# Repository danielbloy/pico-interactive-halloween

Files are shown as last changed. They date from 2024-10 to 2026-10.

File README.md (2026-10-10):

# pico-interactive-halloween

Please see my website [Code Club Adventures](http://codeclubadventures.com/) for more coding
materials.

This project has been moved from https://github.com/danielbloy/pico-interactive/halloween/2024

These videos don't quite do it justice but are good enough to get an idea
of what the finished halloween projects look like.

Halloween
2025 [notes](./2025.md), [pictures](showcase/2025/overview.md), [video on YouTube](https://www.youtube.com/shorts/VWgEQCHVglk)

Halloween 2024 [notes](./2024.md), [video on YouTube](https://youtu.be/h3QauCqTOTw)

Halloween 2023 [video on YouTube](https://youtu.be/a0I0U5x334Y), the full code for Halloween 2023
can be
found at https://github.com/danielbloy/pico-interactive-origins.

My daughter loves Halloween and after Halloween 2022 (she was 8 years old at the
time) we discussed using some of the electronics that I use in my Coding Clubs to
make our house more interactive with sounds and lights. I agreed to this because
how hard could it possibly be? Well it turns out it was a massive undertaking and
very stressful! But she loved it and that was all that mattered.

Once over, we decided to go bigger for 2024 and fix a number of the issues we had
with the 2023 setup. As I knew it'd be a bunch of work I started earlier (March
2024). It was still really difficult to get it all done on time but did look even
more impressive. Yes, she was happy again! The work done for 2024 was implemented
in a fashion to make it generic and reusable for lots of projects. The full
library is available at [pico-interactive](https://github.com/danielbloy/pico-interactive).

The result of the changes during 2024 was this project which contains all the code
and 3D printer files required to build to run the installation. The ambition is
for the installation to be different each year but to provide all the assets here,
along with videos of the finished and working installation.

Whilst [pico-interactive](https://github.com/danielbloy/pico-interactive) works
great, it is a rather hungry framework in terms of RAM and this meant the new nodes
for 2024 still had to have two microcontrollers in them (the Pico 2 was very new
at the time and did not have CircuitPython support in time for me to upgrade). To
solve the resource issues, I started a new project
called [cptkip](https://github.com/danielbloy/cptkip)
which was designed to be more lightweight and resource efficient. The framework
was not mature enough to use in 2025 but did reach maturity in 2026 where it is
introduced in some of the new Mark III nodes. Over time, the Mark 1 and Mark 2
nodes will be replaced with Mark III nodes. The software stack can remain as
`pico-interactive` but running on a Pico 2 or be migrated over to `cptkip` as
functionality allows.

## Networking on all microcontrollers

Each Pico node running CircuitPython and that is connected to wifi needs a
`settings.toml` file that contains:

```
WIFI_SSID = "<WIFI>"
WIFI_PASSWORD = "Password"
```

Please be aware that there ae some inconsistencies about where settings are stored.
This is in part due to the age differences of some of the materials as well
as "how quickly" others have had to be put together. Therefore, there is some
inconsistency as some properties are in `config.py` whilst others are in the code files
themselves. It's usually obvious where the settings are or need to be.

## Structure of the projects

Code/nodes that need to run on desktop computers such as Raspberry Pis or laptops can
be found in the desktop directory. Code designed to run on microcontroller-based nodes
can be found in the microcontroller directory.

As each node haa a dependency on at least one other framework such as `pico-interactive`
or `cptkip` and those frameworks require specific instructions, the nodes are also broken
down by framework.

## Node inventory

### Inside

* Coordinator: Back bedroom, Acer Ubuntu laptop, mains powered - `pico-interactive`
* Projector: Lounge, Lenovo laptop, mains powered - `pico-interactive`
* Dragon eyes and roar: Bedroom, Medion laptop, main-powered - `pico-interactive`
* Dragon fire: Bedroom, Santa catcher, single microcontroller, USB powered - `pico-interactive`

### Sensors

* Ultrasonic 1: Fence, Mark II node, single microcontroller, battery powered - `pico-interactive`
* Ultrasonic 2: Fence, Mark II node, single microcontroller, battery powered - `pico-interactive`
* TODO: Motion Sensor: House, Shelly BLU motion, n/a, battery powered - n/a

### Outside

**Witch hut**

* Fire: Witch hut, Mark I node, dual microcontroller, battery powered - `pico-interactive`
* Cauldron: Witch hut, Mark I node, dual microcontroller, battery powered - `pico-interactive`
    * Also has atomiser in the cauldron.
* Hazel: Witch hut, Mark I node, dual microcontroller, battery powered - `pico-interactive`

**Path**

* Path primary: Path, 2 Mark 2 node, dual microcontroller, USB power - `pico-interactive`
* Path secondary: Path, 2 Mark 2 node, single microcontroller, powered by primary -
  `pico-interactive`

**Graveyard**

* Thunder, lightning, spiders: Witch hut, Mark II node, dual microcontroller, USB power -
  `pico-interactive`

**House**

* Fire: door, custom device, single microcontroller, battery powered - custom software

## Nodes running `cptkip`

These instructions are relevant to the Mark III nodes. The code has been tested
on CircuitPython 9.x and 10.x.

## Nodes running `pico-interactive`

These instructions are relevant to the Mark I and Mark II nodes. The code has been tested
on CircuitPython 9.x.

### How to run the code

For all code designed to run on a Raspberry Pi Pico, ensure that the device is running
CircuitPython and has [pico-interactive](https://github.com/danielbloy/pico-interactive) copied into
the root of the device.

For execution on a Desktop computer, the easiest way to execute the code is by using a
Python virtual environment (either from the command-line or via PyCharm). In both
instances, the virtual environment will need to have the `requirements.txt` installed
and a mapping to a copy of [pico-interactive](https://github.com/danielbloy/pico-interactive).

If running from PyCharm, setup a virtual environment and add `pico-interactive` and
`cptkip` as additional content roots from `File` -> `Settings` -> `Project Structure`.

The following instructions were used to setup such an environment in Ubuntu:

```shell
cd ~/repos
git clone https://github.com/danielbloy/pico-interactive.git
git clone https://github.com/danielbloy/pico-interactive-halloween.git

cd pico-interactive-halloween
python3 -m venv video_venv
source video_venv/bin/activate
pip install -r requirements.txt
export PYTHONPATH=~/repos/pico-interactive

cd desktop/video
python main.py
```

On Windows from a command-line, use the following alternative commands:

```shell
cd C:\Workspace\repos
git clone https://github.com/danielbloy/pico-interactive.git
git clone https://github.com/danielbloy/pico-interactive-halloween.git

cd pico-interactive-halloween
python -m venv audio_venv
audio_venv\scripts\activate  
pip install -r requirements.txt
set PYTHONPATH=C:\Workspace\repos\pico-interactive

cd desktop\audio
python main.py
```

### Specific node running instructions

#### Coordinator, back bedroom, Desktop PC

It is easiest to run the Python code using PyCharm.

Because the coordinator node periodically sends trigger messages to the Dragon
node, if the Dragon node is not running, there will be errors reported in the
coordinator nodes console output. This is fine and will not affect the running
operation of the node. Similarly, if any of the other nodes are missing, when
the coordinator node triggers, errors will be reported for each node that is not
online. Again, this is fine.

The coordinator node needs one copy of `pico-interactive-halloween` and one
copy of `pico-interactive`.

Open the `pico-interactive-halloween` project in PyCharm and create a new
a virtual environment if one does not already exist; `File` -> `Settings`
-> `Python` -> `Interpreter`. Remeber to install the `requirements.txt`

Then add `pico-interactive` as an additional content root from `File` ->
`Settings` -> `Project Structure`.

#### Projector, lounge, Lenovo Windows laptop

It is easiest to run the Python code using PyCharm.

The Lenovo laptop is a Windows-based laptop that runs the video in the lounge.
The easiest way to set this up is to follow the same instructions as for the
Acer Ubuntu laptop that is running the coordinator code.

Replace the contents of `desktop\video\config.py` with those from
`desktop\video\projector_config.py`.

Copy the videos that are to be played into `\desktop\video`.

#### Dragon, bedroom, Medion Windows laptop

This is run on the Medion-laptop which runs Windows. It needs one copy of
`pico-interactive-halloween` and two copies of `pico-interactive`. One copy
of `pico-interactive` should be vanilla whilst the second copy should have
the variable `NETWORK_PORT_DESKTOP` changed from 5001 to 5002 in the file
`interactive/control.py`. This is because we run two python scripts as the
on the machine, one for the eyes (video) and one for the roaring (audio).

Replace the contents of `desktop\video\config.py` with those from
`desktop\video\eyes_config.py`.

Copy the videos that are to be played into `\desktop\video`.

The audio files are stored alongside the source code so do not need copying.

On Windows from two command-line windows, use the following commands to
execute the audio and video programs on the Dragon node (make sure
`pico-interactive2` has the configuration changed to be on port 5002 rather
than 5001):

```shell
cd C:\Workspace\repos\pico-interactive-halloween
audio_venv\scripts\activate  
set PYTHONPATH=C:\Workspace\repos\pico-interactive2
cd desktop\pico-interactive\audio
python main.py
````

```shell
cd C:\Workspace\repos\pico-interactive-halloween
video_venv\scripts\activate  
set PYTHONPATH=C:\Workspace\repos\pico-interactive
cd desktop\pico-interactive\video
python main.py
````

## License

All materials provided in this project is licensed under the Creative Commons
Attribution-NonCommercial-ShareAlike 4.0
International License. To view a copy of this license, visit
<https://creativecommons.org/licenses/by-nc-sa/4.0/>.

In summary, this means that you are free to:

* **Share** — copy and redistribute the material in any medium or format.
* **Adapt** — remix, transform, and build upon the material.

Provided you follow these terms:

* **Attribution** — You must give appropriate credit , provide a link to the license, and indicate
  if changes were made.
  You may do so in any reasonable manner, but not in any way that suggests the licensor endorses you
  or your use.
* **NonCommercial** — You may not use the material for commercial purposes.
* **ShareAlike** — If you remix, transform, or build upon the material, you must distribute your
  contributions under the
  same license as the original.

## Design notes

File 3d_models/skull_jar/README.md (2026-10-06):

# 3D Models for the skull jars

The original skull jars were purchased from [Hobbyraft](https://www.hobbycraft.co.uk/)
for around £2 each and have a mason jar typescrew lid. They are green but we also got
some orange ones. Here is a [link](https://www.hobbycraft.co.uk/light-green-skull-drinking-jar-/6701041003.html).

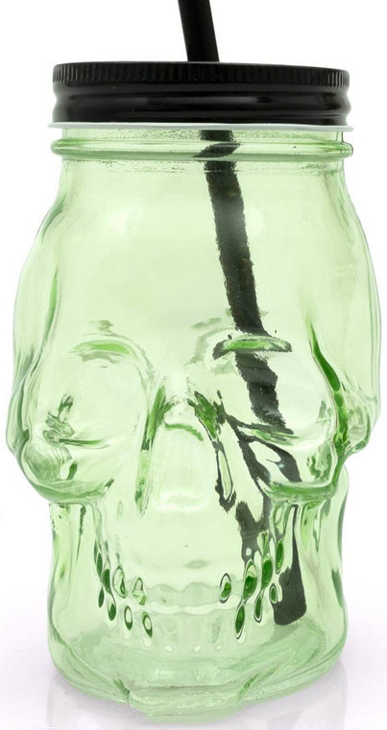
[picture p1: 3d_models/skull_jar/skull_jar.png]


## Skull jar lids

To make the skulls more waterproof and the fittings just generally better, I bought
a fairly basic 3D Printer ([Creality Ender V3 SE](https://www.creality.com/products/creality-ender-3-v3-se)).

I started with searching on [Thingiverse](https://www.thingiverse.com/) and found the
model [Mason Jar Straw Lid by QWERTZ](https://www.thingiverse.com/thing:4432681). I
used that as the basis of my work.

The first change I made was to increase the diameter of the straw hole to 12 mm to
allow me to fit the [12mm cable glands](https://www.amazon.co.uk/gp/product/B07JH2LPZF/ref=ppx_yo_dt_b_search_asin_title?ie=UTF8&th=1)
that will be used to route some [3-core cable](https://www.amazon.co.uk/gp/product/B07HHLGVH5)
through the top. The tool I used to modify the models was [Tinkercad](https://www.tinkercad.com/).

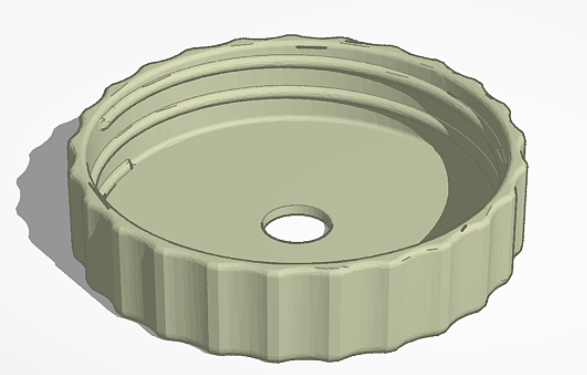
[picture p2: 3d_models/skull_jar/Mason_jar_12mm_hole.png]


## Neopixel ring clip

In the lid of the skull jars there will be a
[32mm Neopixel ring](https://coolcomponents.co.uk/products/8-led-32mm-ring-ws2812b-5050-rgb-led-with-integrated-drivers-adafruit-neopixel-compatible)
containing 8 lovely bright Neopixel compatible LEDs which I purchased from the amazing
[Cool Components](https://coolcomponents.co.uk/). To be able to mount the Neopixel ring
neatly in the top, I designed a simple Neopixel clip in two variants, normal and taller.
The normal clip gives a nice flush tight finish but is a bit fiddly to get in. The taller
one allows more movement and is simpler.

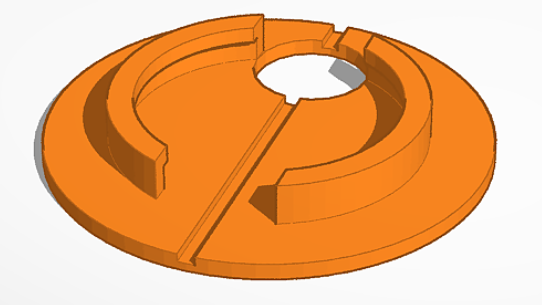
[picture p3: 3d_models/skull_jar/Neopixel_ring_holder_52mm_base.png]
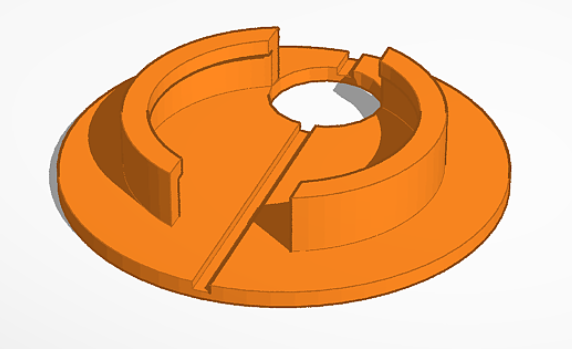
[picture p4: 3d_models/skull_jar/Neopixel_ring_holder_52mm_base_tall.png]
 

## Attaching the Neopixel rings to the jar lid

Holding the Neopixel ring clip in place required another clip that went from the jar lid and
extended downwards. There needs to be enough space between the jar lid and the Neopixel clip
to connect everything up so I experimented with different heihgts and settled on a lowish profile
that did not extend too far below the top of the skull jar.

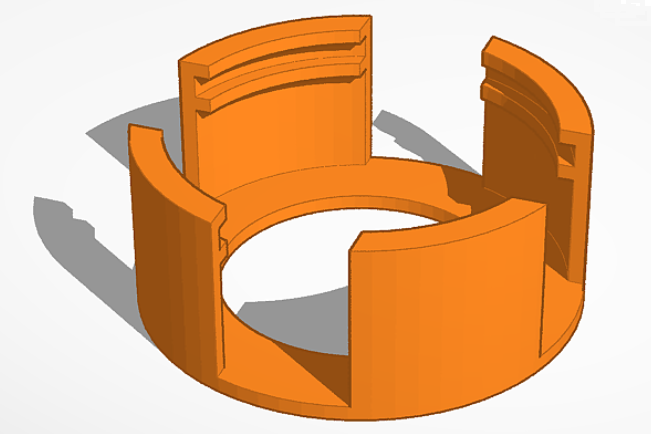
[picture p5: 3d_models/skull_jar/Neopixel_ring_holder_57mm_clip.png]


This clip was then attached to the jar lid to make a single model that can be printed.

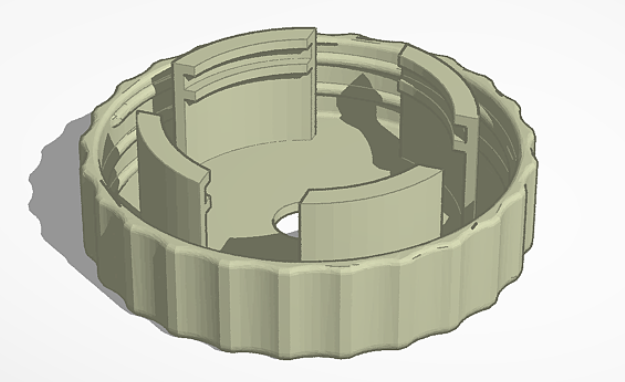
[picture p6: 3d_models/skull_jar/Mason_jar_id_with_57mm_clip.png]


## Wiring everything up

Space between the jar lid and the Neopixel ring clip is tight but when assembled gives a nice
neat finish. To connect the incoming 3-core wire to the Neopixel ring I used an electrical
connector block. The ones I used were simple 3 amp ones that can be purchsed from any electrical
retailer. I got mine online from [Amazon here](https://www.amazon.co.uk/gp/product/B0BTPFWNVF).

The Neopixel rings come with JST SM connectors already attached. The simplest method to
attach the Neopixel ring to the 3-core cable is to buy some extra [JST SM connectors](https://www.amazon.co.uk/gp/product/B07K2L814N)
For simplicity, you can cut the output connector off the Neopixel ring and use that
but as I wanted to reuse my Neopixel rings for other projects, I bought some extra
connectors.

## Plain skull jar lid

For 2026, I added some more skulls to the graveyard part of the display. These are spare
skull jars with a flickering candle in them on mounts. For these, I prepared a simple
plain lid.

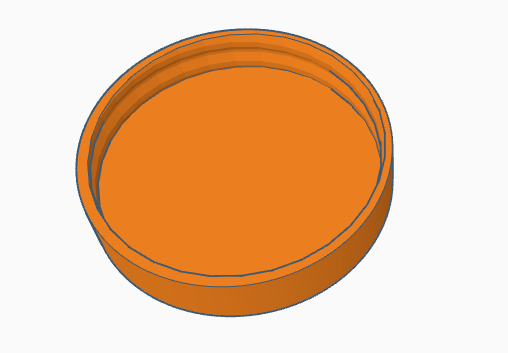
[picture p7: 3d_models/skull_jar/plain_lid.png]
plain jar lid


## Skull Mount

In previous years, the skulls have been laid out on the path. This unfortunately means they
sometimes get knocked over by enthusiastic children. To address this, for 2025 I designed a
simple mount that the skull goes in which can then be placed in the borders which are either
side of the path. The 2025 mount was okay but a little fragile and required nuts, bolts and
purchasing 21mm tubing. In 2026 I redesigned the mounts as a 3-piece unit. It is completely
3D printed, screws and pushes together and requires no other parts to be purchased.

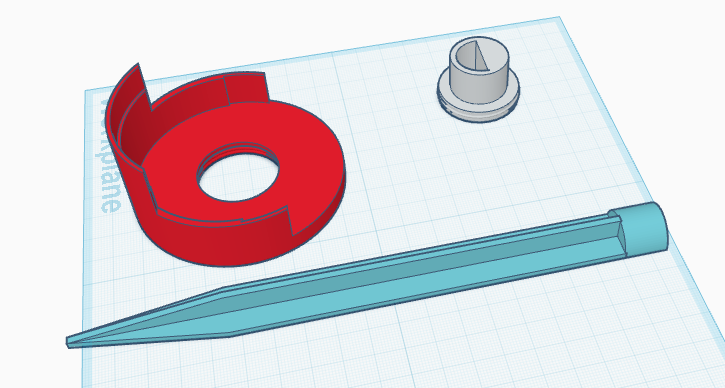
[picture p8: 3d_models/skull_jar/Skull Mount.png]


## All 3D model files

* [Mason Jar with 12mm hole](./Mason_jar_12mm_hole.stl)
* [Neopixel ring clip, normal](./Neopixel_ring_holder_52mm_base.stl)
* [Neopixel ring clip, taller](./Neopixel_ring_holder_52mm_base_tall.stl)
* [Neopixel clip holder](./Neopixel_ring_holder_57mm_clip.stl)
* [Mason jar with Neopixel clip holder](./Mason_jar_id_with_57mm_clip.stl)
* [Plain jar lid](./plain_lid.stl)
* [Skull mount](./Skull%20Mount.stl)

## Bill of materials

There are 12 skulls in total (6 skulls on each side of the path).
You will need to purchase enough items to build all 12 skulls.

* [3-core cable](https://www.amazon.co.uk/gp/product/B07HHLGVH5)
* [Skull jar](https://www.hobbycraft.co.uk/light-green-skull-drinking-jar-/6701041003.html)
* [12mm cable glands](https://www.amazon.co.uk/gp/product/B07JH2LPZF/ref=ppx_yo_dt_b_search_asin_title?ie=UTF8&th=1) 
* [32mm Neopixel ring](https://coolcomponents.co.uk/products/8-led-32mm-ring-ws2812b-5050-rgb-led-with-integrated-drivers-adafruit-neopixel-compatible)
* [Terminal blocks](https://www.amazon.co.uk/gp/product/B0BTPFWNVF)
* [JST SM connectors](https://www.amazon.co.uk/gp/product/B07K2L814N)
* [Mason jar with Neopixel clip holder](./Mason_jar_id_with_57mm_clip.stl)
* [Neopixel ring clip, normal](./Neopixel_ring_holder_52mm_base.stl)
* [Skull Mount](./Skull%20Mount.stl)
* [21 mm outside diameter tube](https://www.amazon.co.uk/dp/B0BLCFMSPG?th=1)

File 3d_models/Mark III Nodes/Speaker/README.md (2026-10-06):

# 3D models for the Mark III speaker nodes

The Mark III nodes are a new design where all parts are 3D printed and
can be screwed together. This makes it much easier to assemble the devices
and use the same parts for different types of boxes. The first version of
the speaker box has:

* A housing for a speaker - light blue parts
* A lid for the speaker - dark blue parts
* A mount for the circuit board, including clip - red parts
* A housing for the circuit board and base lid - green parts
* A base internal cover that has holes for buttons, cables and friction clip for a 4 x AA battery pack - orange parts
* An extended base lid with holes for cable glands - yellow parts
* A stand - pink part

There are multiple variations of the orange, blue and yellow parts to cater
for different requirements.

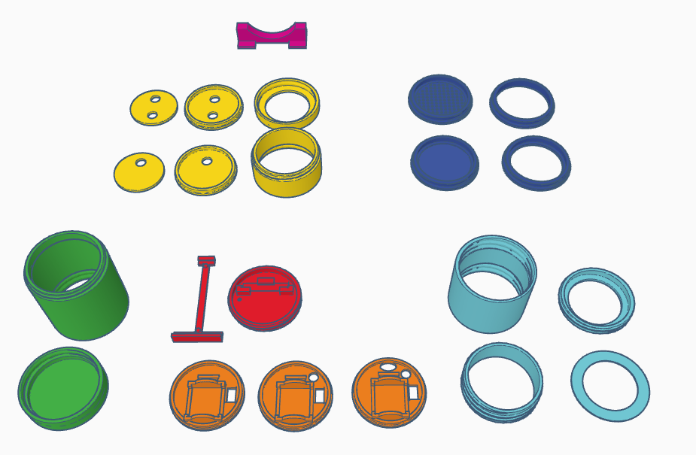
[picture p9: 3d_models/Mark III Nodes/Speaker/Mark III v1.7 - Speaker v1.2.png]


## Assembly

This is straightforward.

Assemble the speaker housing (light blue). This example uses an open speaker lid (dark blue).
Do not fit the speaker housing screw yet. If fitting an actual speaker, leave the lid loose
until fitting is completed.

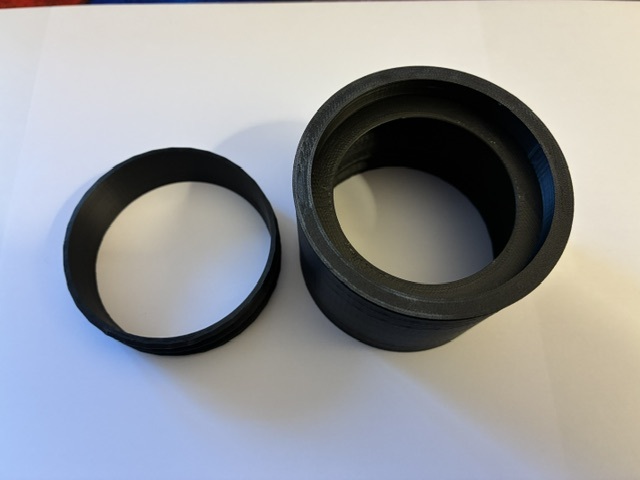
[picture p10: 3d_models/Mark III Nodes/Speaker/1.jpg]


Mount the circuit board into the holder and the holder into the screw part (red parts).

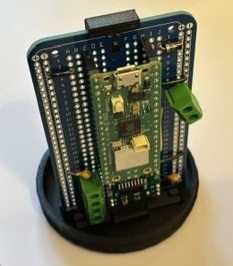
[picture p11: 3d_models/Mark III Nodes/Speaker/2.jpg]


Screw the circuit board assembly into the speaker housing, routing any wires through the
access hole. Then take the remaining threaded part from the the speaker housing and screw
that in to firmly secure the circuit board holder.

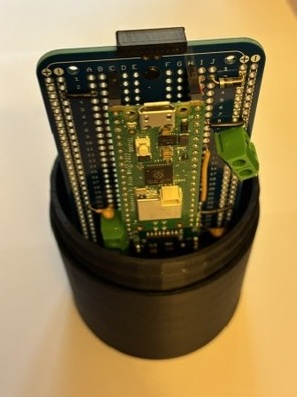
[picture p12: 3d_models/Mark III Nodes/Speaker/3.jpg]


Screw the housing over the circuit board (green parts). Fit the desired internal base cover
(orange parts). this example is for a battery only unit so only has a rocker switch hole.

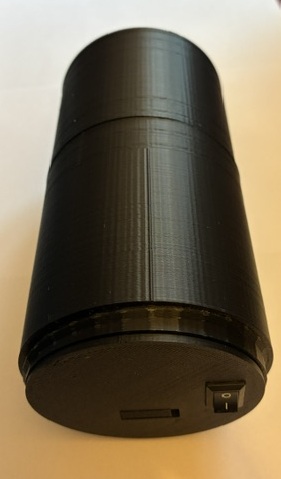
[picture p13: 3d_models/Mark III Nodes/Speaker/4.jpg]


Screw in the appropriate base (green or yellow parts). The vertical example below has the green base whereas the example laying flat has a single hole for a gland. Please note that
when using the yellow parts, the device is slightly longer.

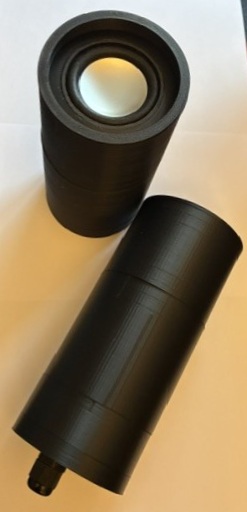
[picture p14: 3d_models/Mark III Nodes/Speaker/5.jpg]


## Bill of materials

* [53 mm speaker](https://www.amazon.co.uk/dp/B09ZL4YCZ8)
* [12mm cable glands](https://www.amazon.co.uk/gp/product/B07JH2LPZF/ref=ppx_yo_dt_b_search_asin_title?ie=UTF8&th=1)
* [4 x AA battery housing](https://www.amazon.co.uk/dp/B0FPG2N1CV)
* Rocker switch

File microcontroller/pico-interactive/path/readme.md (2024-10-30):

NOTE: Rename this to code.py on the primary node network microcontroller.

This node runs:

* Network communications

It is connected to two other nodes which each control the skulls for one side of the path:

* A local path node on the same board:
    * Controls 6 x skulls, 2 x speakers (plays the dong sounds)

* A remote path node on the other side of the board:
    * Controls 6 x skulls, 2 x speakers (plays dragon and lion sounds)
    * Has an ultrasonic sensor to check for a trigger.

In terms of communications:

* This node can communicate with the network, indicating a trigger (or force trigger).
* This node can trigger both the local and remote nodes using a single wire (as a button)
* The local path node does not communicate back to this node at all.
* The remote path node can indicate a trigger event (but does nothing about it itself)

The local path node can be triggered by:

* The ultrasonic sensor
* A network message
* A button press (either node)

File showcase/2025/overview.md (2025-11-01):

# Overview of 2025

This year, I've taken two days off during half-term to allow
a little more time to prepare the halloween display. To see
progress, I've taken a few photos as I've gone along. Enjoy.

## Day 1 - Thursday 30th October

This shows the triangular flower bed containing lots of
pumpkins that have been neatly carved by Amelia and
Lesley. The skeleton is also out sunbathing and toasting a
marshmallow of two. On the left you can see the car which
is where the witches house (gazebo) will go.

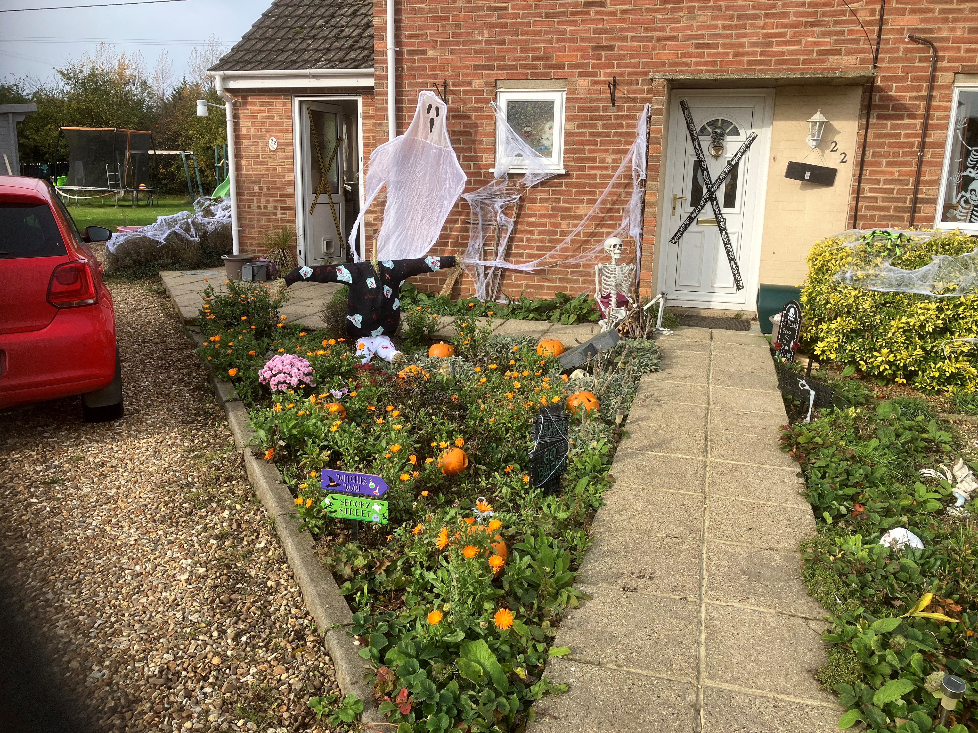
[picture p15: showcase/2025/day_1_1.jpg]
Day 1 - Image 1


This shows the pathway and front door. The path skulls have
not been installed today as that is one of tomorrows jobs.

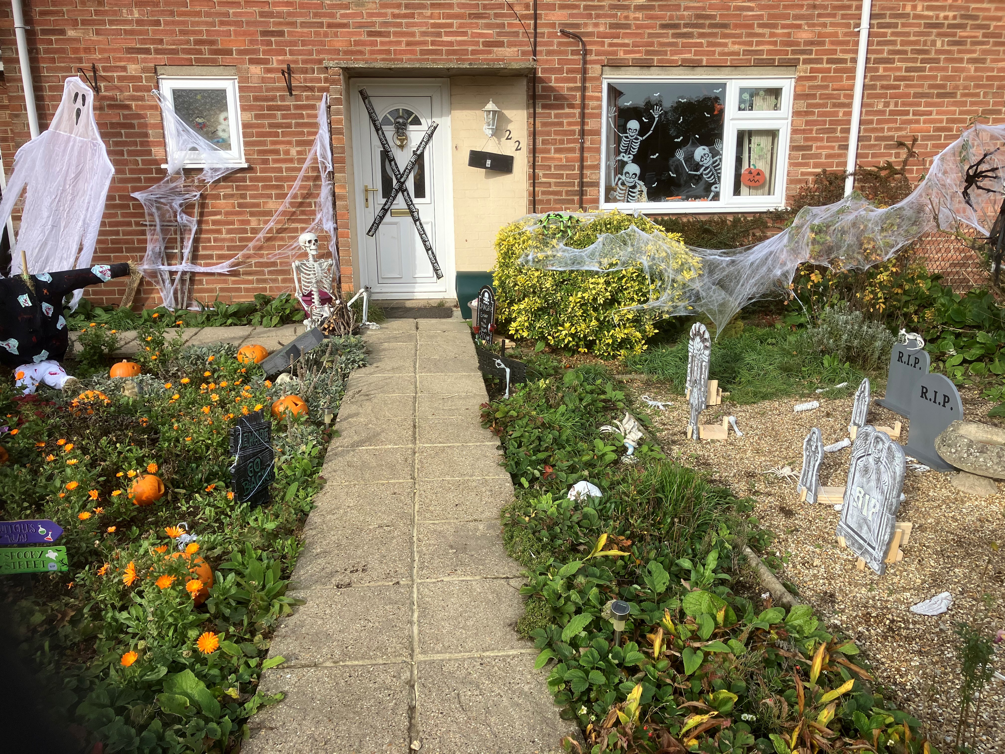
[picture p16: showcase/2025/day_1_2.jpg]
Day 1 - Image 2


And the graveyard with the head stones all set out. Some of
the spiders have been put out but tomorrow will see the smoke
machine, projectors and thunder and lightning effects installed.

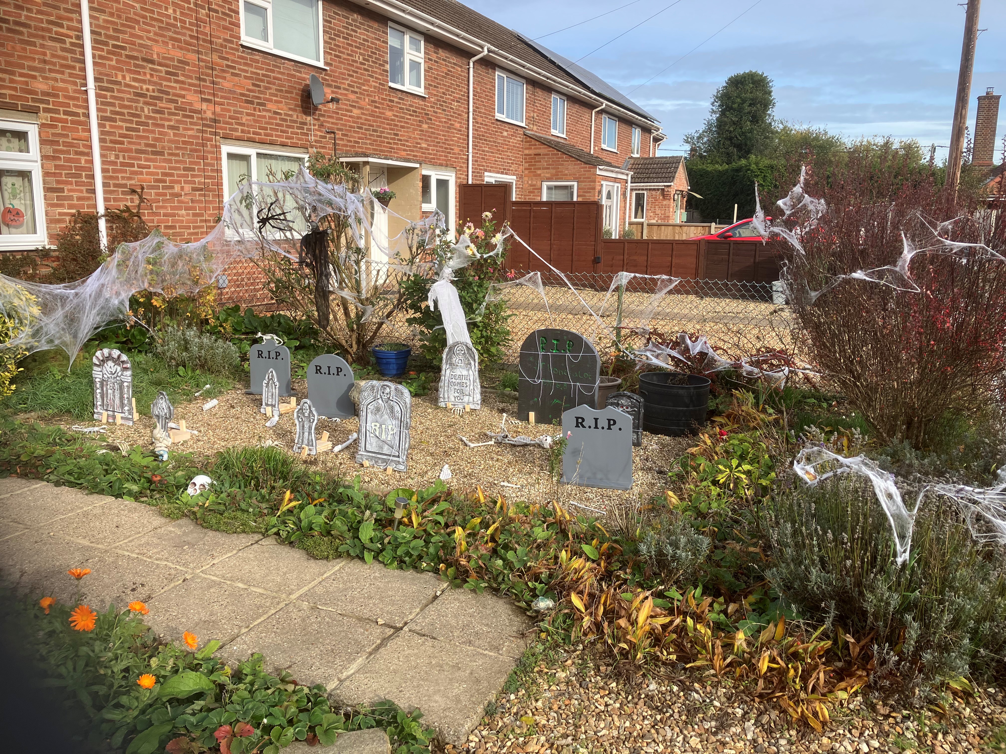
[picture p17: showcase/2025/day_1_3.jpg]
Day 1 - Image 3


## Day 2 - Friday 31st October

This shows the gazebo on the drive which is being converted
into the witches house. The weather was not playing nice with
quite high gusts of wind. This meant I had to spend a lot of
time with extra ropes, weights and supports.

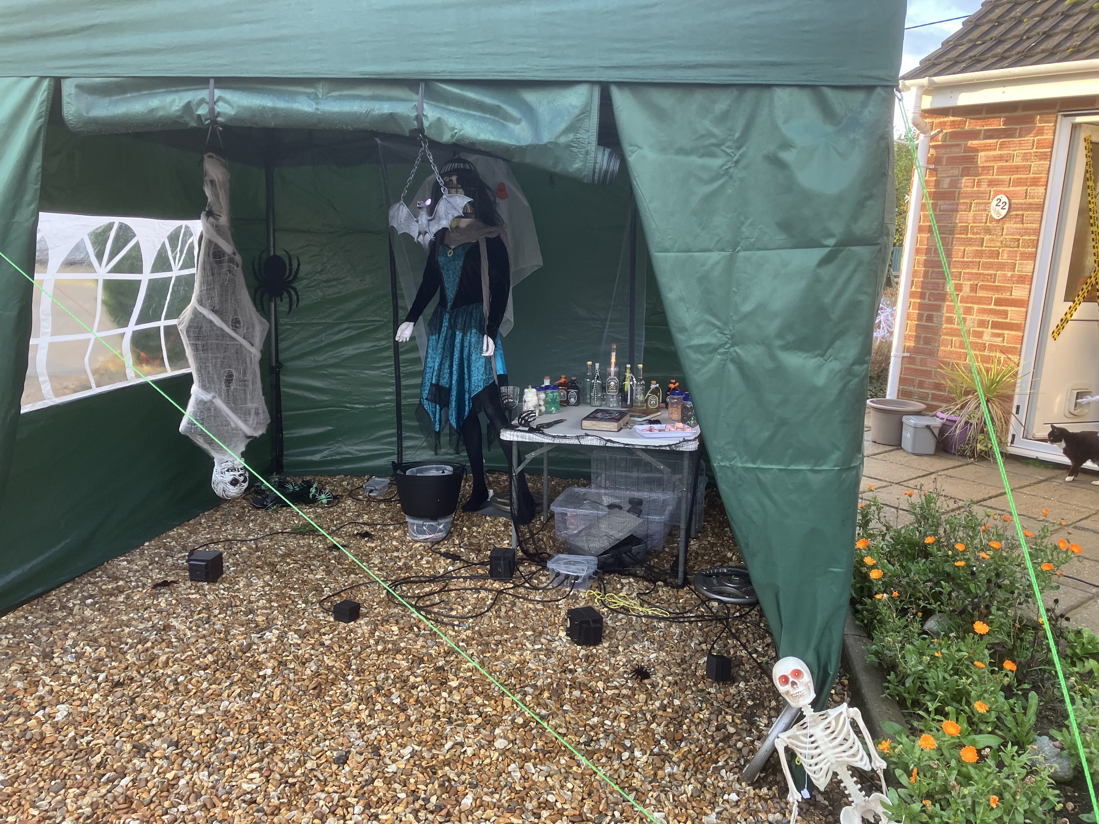
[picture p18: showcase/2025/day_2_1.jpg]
Day 2 - Image 1


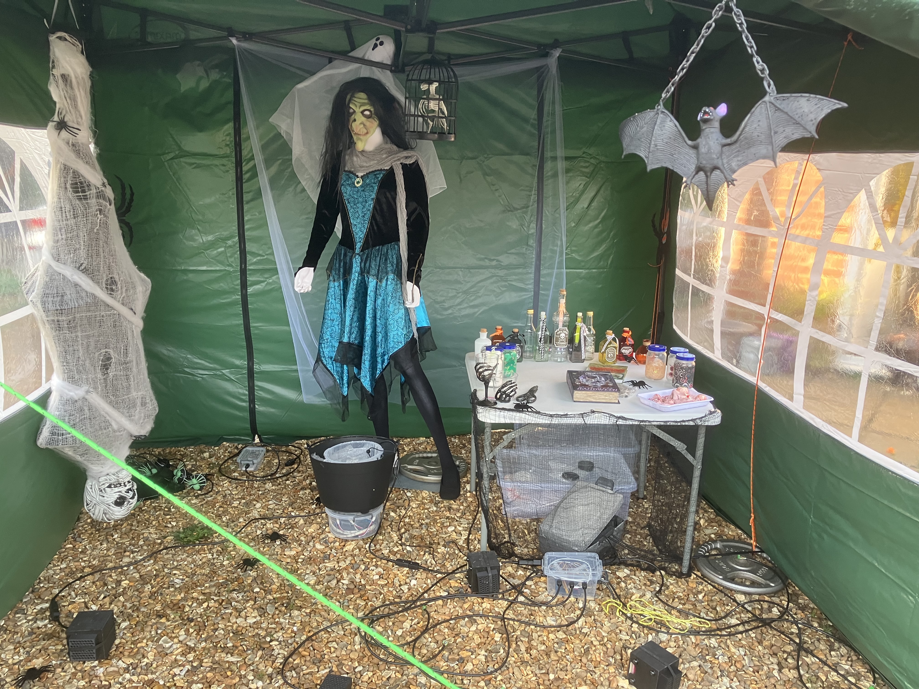
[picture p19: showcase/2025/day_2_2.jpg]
Day 2 - Image 2


Close up of Mr Bones toasting marshmallows on the fire prop
that I made for the school play earlier this year.

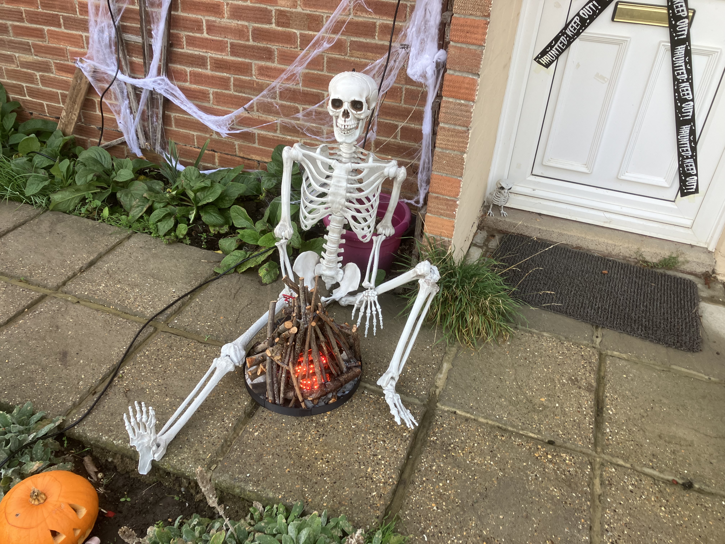
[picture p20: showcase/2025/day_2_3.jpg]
Day 2 - Image 3


The big mess of wires that is the main controller unit for
the right hand side of the path.

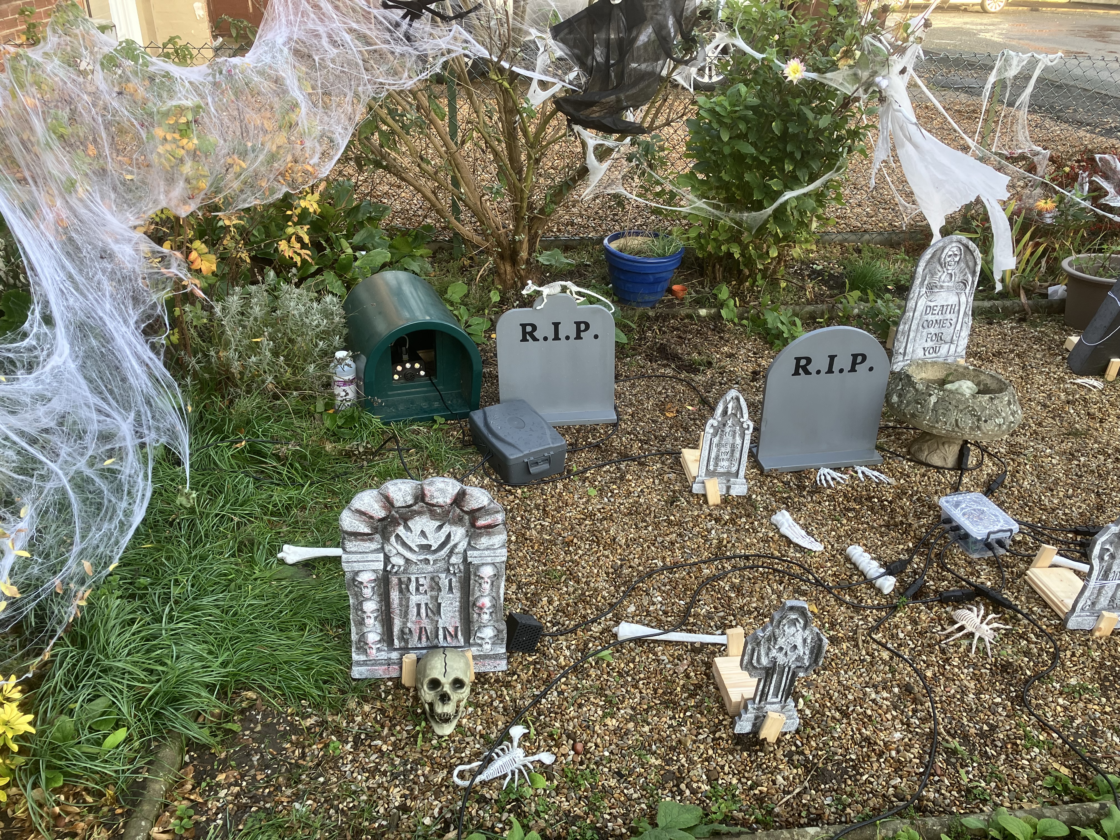
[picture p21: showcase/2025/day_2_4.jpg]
Day 2 - Image 4


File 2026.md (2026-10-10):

# Halloween 2026

2026 sees the introduction of the new Mark 3 boxes which are entirely
3D printed and more versatile than both the previous Mark 1 and Mark 2
boxes as they screw together in sections. For the 2026 display, we will
be adding at least 3 boxes and (if time allows) replacing the 3 Mark 1
boxes with Mark 3 boxes. The current Mark 3 boxes are all battery powered
for ease of installation and use. A future enhancement is to support USB
power.

The Mark 3 boxes also come with the entirely new software stack that is
more efficient so only a single Pico is required per box rather than the
2 Picos required in the Mark 1 and 2 boxes. We have also prototyped using
Pico 2 and ESP32-S3 boards that are both more powerful and have
significantly more RAM available. The more powerful devices, improved
software stack and improved boxes have opened up a lot of options for
future enhancements to the display.

The new software stack and boxes have taken a significant amount of time
to prepare so there are no major changes to the layout of display, which
remains identical in terms of overall to the 2025 display. We've just
added more stuff. For a description of how the installation area is
arranged and split into "zones", please refer to [layout](./layout.md).

## Priority list of tasks

* [x] Test all devices to make sure they work.
* [x] Add all required functionality to `cptkip` so it can be used in the display.
* [x] Build 3 x new Mark 3 boxes that have sound through PWM to support `pico-interactive`.
* [x] Implement single board code (Pico 2W) for `pico-interactive`.
* [ ] Migrate Fire node to Mark 3 node.
    * [x] Migrate code to pico-interactive single node
    * [x] Migrate code to cptkip
* [ ] Migrate Cauldron node to Mark 3 node.
    * [x] Migrate code to pico-interactive single node
    * [x] Migrate code to cptkip
* [ ] Add additional Mark 3 node to display.
* [ ] Repurpose the 2 replaced Mark 1 File and Cauldron nodes to sound nodes only.
* [x] Build 3 x new Mark 3 boxes that have sound through I2S, using `cktip`.
* [x] Implement the Halloween-specific networking code for `cptkip`.
* [ ] Add the 3 x new Mark 3 boxes to the display.
* [x] Purchase new Shelly sensor platform to detect victims.
* [ ] Implement a new sensor platform to detect victims.
* [x] Completely new Skull mounts.
* [x] Design skull lid for flickering LEDs.

## Stretch list of tasks

* [x] Extend the Mark 3 boxes to support NeoPixels.
* [x] Extend the Mark 3 boxes to be powered by USB.
* [ ] Replace the Mark 1 boxes for the witch with new Mark 3 boxes.

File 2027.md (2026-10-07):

Priority list of items to do:

* [ ] Dismantle the three remaining Mark 1 nodes and rebuild as Mark 3 sound nodes.
* [ ] Dismantle the two ultrasonic nodes and reuse as Mark 3 nodes to replace spiders.
* [ ] Build better fire for cauldron.
* [ ] Replace spider and lightning node with better implementations.
* [ ] Setup Raspberry Pis to run Python script automatically upon startup.
* [ ] Add capacitors to lightning box to avoid reset due to drain from power spike.

Stretch items:

* [ ] Setup a Raspberry Pi 3A+ to run audio and trigger other devices via WiFi.
* [ ] Add another projector.

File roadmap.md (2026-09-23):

# Roadmap

* Support for Raspberry Pi (3A+ and Zero 2W) with `cptkip` and `pico-interactive`
* Add LCD screen support to make projectors for floating eyes.
* Add support for Video out using Pico 2s to drive displays.
* Replace all remaining Mark 1 boxes.
* Replace the Mark 2 boxes.
* Come up with a much better power distribution system for the entire display
  based on mains power distribution to each zone.
* Migrate all primary networking and control to Raspberry Pi devices.
* Coffin that shakes and makes noises
* Boxes that open with eyes

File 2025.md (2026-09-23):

# Halloween 2025

Both the 2023 and 2024 displays took a massive amount of time to design and build. This was
in part because I was learning what worked and what didn't as I went along as well as building
everything from scratch. The amount of time invested was also so significant that it made it
very difficult to progress other projects that I'm working on. So for 2025, I'm focussing on
using what I already have and turning that into a more coherent display. Crucially, part of the
display will be covered to protect it from the elements and this opens it up to much more
impressive display possibilities. It also means my daughter can take a larger part in designing
and building the project; particularly the witches house.

Also, as I've learnt more about what works and what doesn't, I'm designing all-new control
boxes and a completely new software stack using everything I've learnt so far. Unlike previous
years I'm not rushing to put them into production. Rather I will be working on the boxes, the
software stack and the new circuit boards over 2025 and through into 2026 with a view to replace
the older 2023 boxes first. If you are interested, the new software stack can be found at
[cptkip](https://github.com/danielbloy/cptkip).

## Key changes from previous years

For a description of how the installation area is arranged and split into "zones", please
refer to [layout](./layout.md).

This year we are going for a different arrangement to the display to avoid the concept getting
stale. The primary part of the display is a new witches hut that will be a covered display
(its a 3m by 3m gazebo).

## Priority list of tasks

* [x] Undertake a full inventory of devices.
* [x] Design and manufacture new eyes.
* [x] Design and manufacture skull holders.
* [x] Add support for playing sounds at the same time as movies in Video node.

## Path, sensors and skulls

This part of the display will be much the same as 2024. There will be 6 skulls down
each side of the path. These will flicker when turned on. They will come on in time
to the bells in the primary audio. There are additional dragon and lion sound effects
and for 2025 these will be changed. The dragon effects will be removed so they can be
reused with the bedroom dragon. Another minor change to 2024 is that the skulls will
be mounted on brackets rather than stood on the path. This is to avoid them being
accidentally kicked over.

The sensors will be at the entrance to the path and trigger the display.

Display elements:

* Sensors at the path entrance.
* Skulls down each side of the path, connected by a long cable for synchronisation.

Outstanding items:

* [x] Finish the design of the skull mount.
* [x] Manufacture the skull mounts.
* [x] Review the sounds that are played.

## Square shingle, graveyard

The square shingle is to the right-hand side of the path and will be completely
different for 2025. The entire area will be a graveyard (in the 2024 display, the
graveyard was spread across the full front garden). A smoke machine will be
installed close to the house using ice to keep the smoke at a low level and avoid
full dispersal. The lightning box will be installed close to the smoke machine
for an additional effect. One more sound box will be installed to provide
background sound effects.

Display elements:

* Gravestones.
* Skeletons, spiders.
* Smoke machine.
* Lightning box.
* Raspberry Pi background sound box.

Outstanding items:

* [x] Purchase smoke machine and liquid
* [x] Purchase additional skeleton and bones.
* [x] Varnish the wooden gravestones.
* [x] Buy additional gravestones.
* [x] Construct robust mounts for gravestones.
* [x] Select sounds.
* [x] Build Raspberry Pi Graveyard audio box.

## Lounge, projector

The lounge is on the right-hand side of the path behind the square shingle and
will be the same setup as 2024 with a single projector and speakers. This will
project videos of dancing villains and skeletons.

Display elements:

* Raspberry Pi, Projector and speakers.

Outstanding items:

* [x] Review the videos to display and timings.
* [x] Purchase projector stand.

## Large bedroom, dragon attractor

The large bedroom is on the right-hand side of the path above the lounge. This
will be the same as 2024 and contain the dragon eyes on a TV which will be setup
as a permanent attractor. The dragon noises used elsewhere in the installation
will be removed so they can be used solely as part of this display. The TV will
be decorated so that it looks like a dragon and a new fire effect will be added
in the background using the 2024 Santa Detector item.

The dragon itself requires two applications to run on a single Desktop device.
One application runs the eyes and the second application controls the sounds.
The reason these are two applications is so that the same video can be used on
a loop but the dragon sounds can be randomly played. With two applications
running, each will need its own copy of `pico-interactive` so that unique ports
can be used for each application (as defined in
`pico-interactive/interactive/control.py`).

Display elements:

* Raspberry Pi, TV for dragon eyes.
* Raspberry Pi with speakers for dragon sounds.
* Fire effect using microphone to adapt to noise.

Outstanding items:

* [x] Add background fire effect using Santa Detector.
* [x] Build an application based on Video to play audio for Raspberry Pi/PC.
* [x] Purchase speakers.
* [x] Add dragon sound effects.

## Triangle flower bed, pumpkin patch

The triangle flower bed is to the left of the path and will be an all new display
for 2025. It will be a pumpkin patch with a pumpkin head scarecrow. The pumpkins
will have atomisers to provide a light smoking effect and the scarecrow will have
LCD screens for eyes. The LCD screens will be a remake of the MakeCode Arcade eyes
used in the creepy head for the 2023 and 2024 displays. The pumpkin head scarecrow
is going to be built by Amelia. Ideally we'd have another sound box to allow for
sounds to be played.

Within the `microcontroller/makecode_arcade/eyes` directory are some images
that show the box used to hold the eyes for the 2023 and 2023 creepy head along
with the new 3D printed mount and circuit board that will be used for the 2025
pumpkin head scarecrow. The 2025 variant is much more compact!

Display elements:

* Carved pumpkins with team lights

Outstanding items:

* [x] Build LCD eyes (MakeCode Arcade) for pumpkin head scarecrow.
* [ ] Build atomising extension cables for misters.
* [ ] Test atomising misters.
* [x] Carve pumpkins and install tea lights.

## Gravel drive, witches house

The witches house is a completely new installation for 2025. It will be mostly
made up from repurposed components from other parts of the display from 2024
and new items made. The witches house will have a table and Hazel (our resident
mannequin) made up as a witch. Amelia will choose and make most of the decorations.
There will be a cauldron sitting above a fireplace. For 2025, the fireplace will
be a new item that was made for the Denver Primary School play. It'll need fixing
up to repair some of the damage made by the children in the play. The cauldron will
need to be placed on a stand above the fire and will have lights and the atomiser
from 2024 to give a smoke effect.

Because the wi-fi range of the Picos could be an issue, this installation may need
to be driven by a Raspberry Pi.

Display elements:

* Hazel the witch.
* Cauldron and fire.
* Witches table.

Outstanding items:

* [x] Purchase new gazebo.
* [x] Review the witches sounds.

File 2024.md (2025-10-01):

# Halloween 2024

## Power distribution

In 2023, all nodes (apart from the coordinator) were battery powered. This
offered great flexibility as to positioning but required a lot of batteries
and meant the whole system could not easily be turned off (or on) with a
single switch. For 2024, I looked for more mains powered distribution to
solve this problem.

## New nodes

### Sensor

Separate boxes for sensors to make the entire system automatic. It mostly worked.

### Spiders

This is something that was prototyped for 2023 but we ran out
of time to implement. In essence, a node controled LEDs that are drilled
into the eyes of some spiders and made to pulse on command. However, the
final implementation reused a lot of parts from the 2023 path nodes and
used NeoPixels and a 3D printed holder that projected eyes and lines onto
glow-in-the-dark spiders. It was very effective.

### Projector

This was really easy to add and very effective.

### TV

This was used as an attract with blinking eyes. Very easy to add and very
effective.

### Thunder and lightning

This was integrated into the spiders node to save
  time. That was a mistake due to power draw.

## Replaced nodes

### Path

Both the left and right path nodes were fragile and the wireless
communications introduced tiny delays that were noticeable when trying to
sync their actions. These two nodes will use 6 separate rings of NeoPixels
each (1 per skull) rather than one single chain of NeoPixels to control
chained to the 6 skulls. The communication between the nodes will be direct
(likely over UART cable but possibly Wi-Fi) to remove delay. The nodes
will not need to communicate via the coordinator as they will each have
an ultrasonic sensor so become largely autonomous.

## Upgraded nodes

### Witch

This had an atomiser added to the cauldron to give a more realistic effect.
It reused 3 of the 2023 boxes for multiple sounds; though the 2023 boxes are
much quieter than the 2024 boxes.

We will also added a life-sized witch (actually a mannequin wearing a witches
outfit).
  
## Original nodes

### Creepy head

This is actually a MakeCode Arcade based board with screens so a completely different
kind of node. It does have a second Pico based board that drives the speaker in the
head but it just plays a background sound on repeat.

## Evaluation

Whilst bigger and more impressive, the 2024 installation highlighted new issues.
Even though the re-architecting of the code in the
[pico-interactive](https://github.com/danielbloy/pico-interactive) project made
it better tested and more flexible, it also increased the RAM requirements so the
nodes still required multiple Pico microcontrollers to work. That resulted in me
starting work on a newer more lightweight and modular framework called
[Circuit Python Toolkit for Interactive Projects (CPTKIP)](https://github.com/danielbloy/cptkip).
The newer "boxes" which control the electronics built for 2024 were much more robust
and easy to connect together than the 2023 "boxes" but the tradeoff was them being
much more bulky and taking a significant amount of time to build. I guess you live
and learn.

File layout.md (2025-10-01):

# Layout

The display area is split into `zones` as follows (left and right sides are from the
perspective of facing the house). Note, over time, more `zones` have been added to
the display area so all installations do not necessarily use all `zones`.

* Path
* Door, end of path
* Square shingle, right of path
* Lounge, right of path
* Large bedroom, above lounge, right of path
* Left triangle flower bed left of path
* Small bedroom, above triangle flower bed, left of path
* Shingle drive, left of triangle flower bed
* Cabin, back of shingle drive.

The floor plan looks like this (not to scale):

```text
        Small Bedroom   Door     Large Bedroom
                      |      |       Lounge
          ------------+      |
< Cabin       Path           |
          +-----------+      +--------------------+
          |           |      |                    | 
           | Triangle |      |                    |
            |  Flower |      |                    |
             |    Bed |      |       Square       |
              |       |      |       Shingle      |
               |      | Path |                    |
    Gravel      |     |      |                    |
     Drive       |    |      |                    |
                  |   |      |                    |
                   |  |      |                    |
                    | |      |                    |
                     ++      +--------------------+
```

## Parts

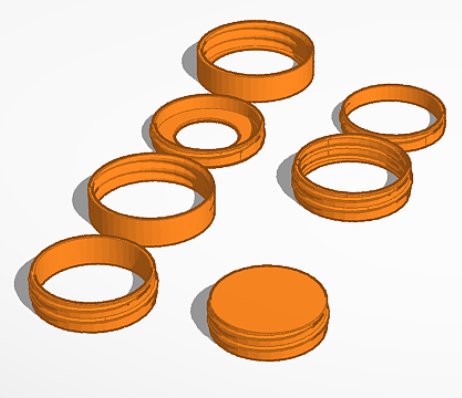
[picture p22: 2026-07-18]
3d_models/Mark III Nodes/screwable parts.png

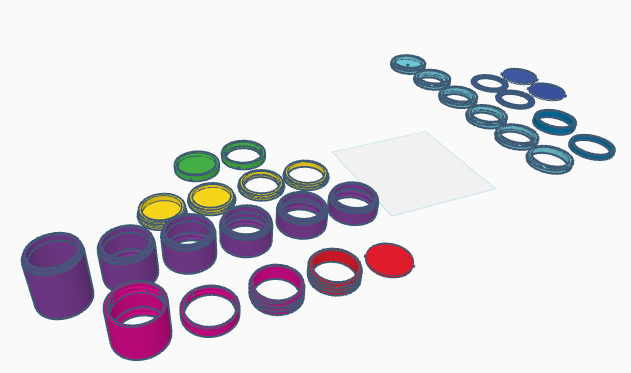
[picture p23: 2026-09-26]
3d_models/Mark III Nodes/Mark III v1.7 - baseline parts.png

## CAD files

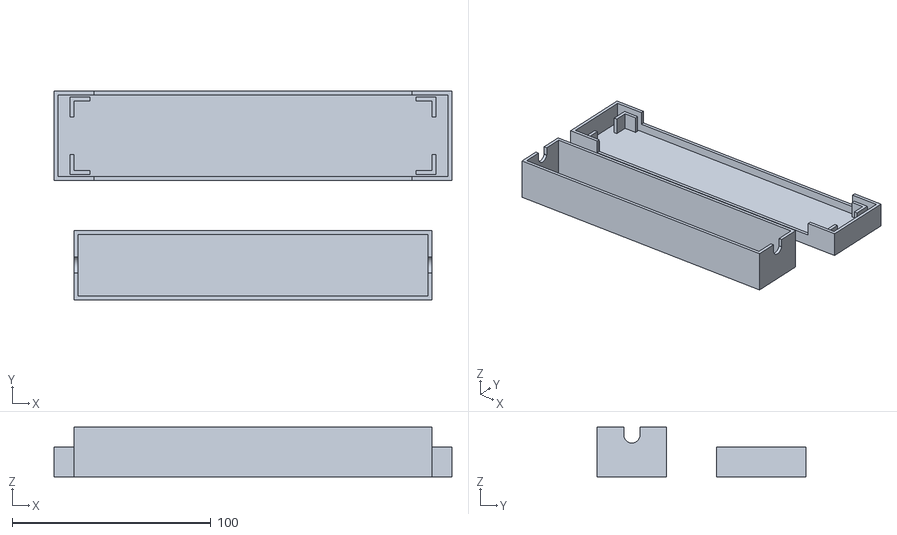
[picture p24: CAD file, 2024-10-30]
3d_models/connectors/Connector Box.stl
200.0 x 105.0 x 25.0

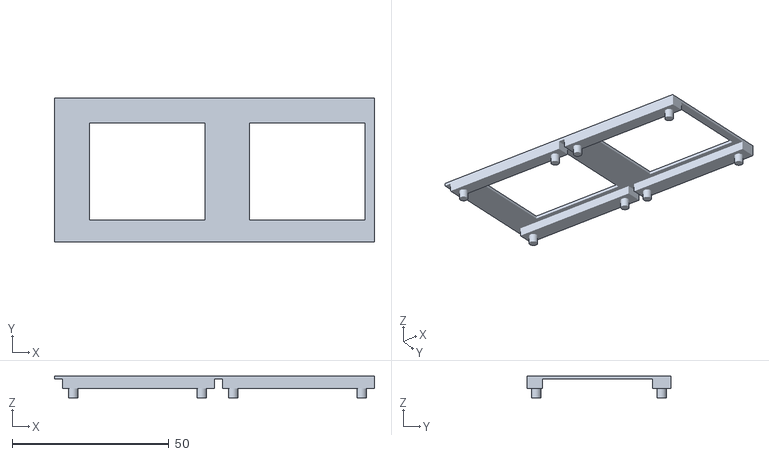
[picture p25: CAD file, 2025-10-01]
3d_models/eyes/Screen cover double.stl
102.0 x 46.0 x 7.00

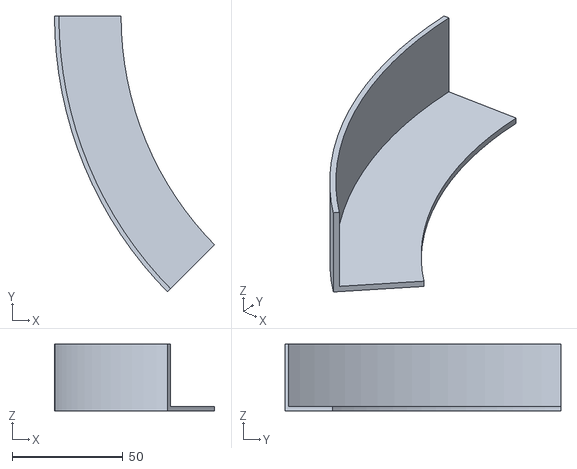
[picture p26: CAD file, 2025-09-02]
3d_models/fire/Eigth turn.stl
72.1 x 124.1 x 30.0

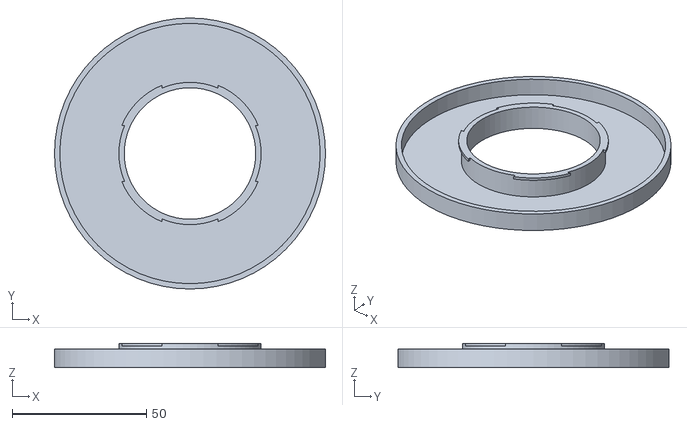
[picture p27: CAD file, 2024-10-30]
3d_models/lightning/24 x Neopixel ring cover 92mm.stl
101.0 x 101.0 x 9.00

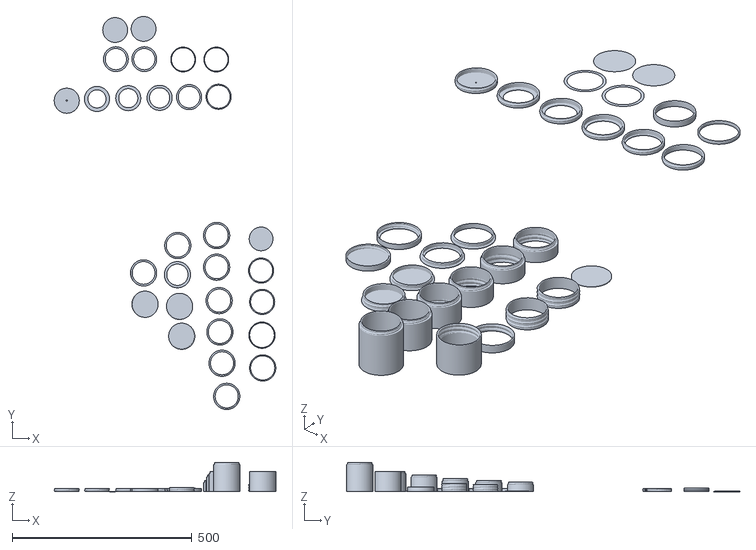
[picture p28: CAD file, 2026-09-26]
3d_models/Mark III Nodes/Mark III v1.7 - baseline parts.stl
616.0 x 1092.0 x 81.0

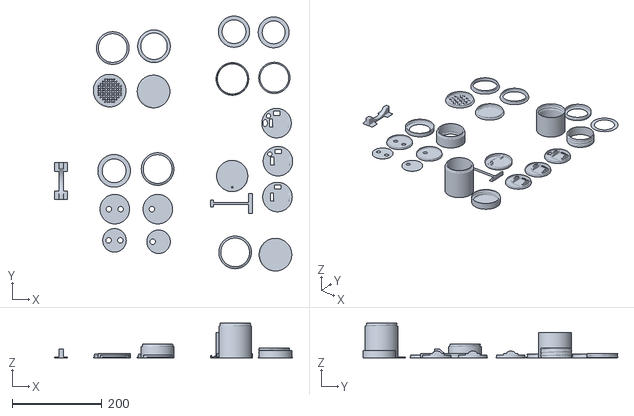
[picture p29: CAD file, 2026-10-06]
3d_models/Mark III Nodes/Speaker/Mark III v1.7 - Speaker v1.2.stl
532.0 x 569.0 x 77.0

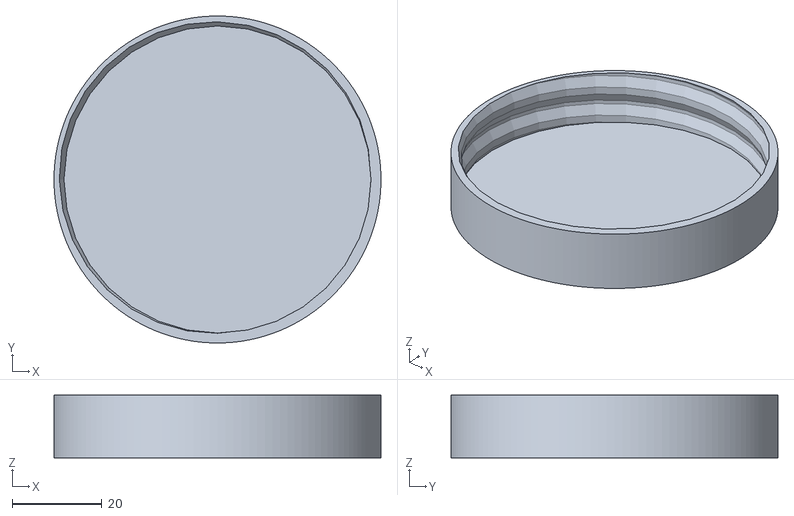
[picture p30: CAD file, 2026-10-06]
3d_models/skull_jar/plain_lid.stl
73.0 x 73.0 x 14.0

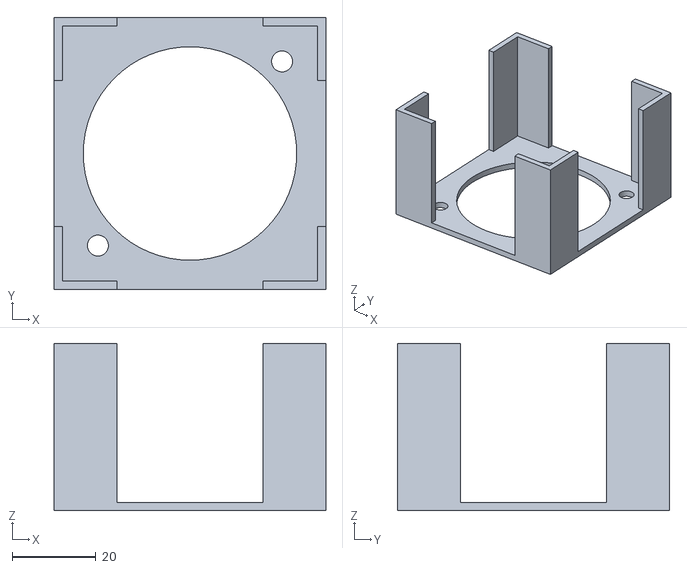
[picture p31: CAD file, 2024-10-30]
3d_models/speaker/Speaker Clip.stl
65.0 x 65.0 x 40.0

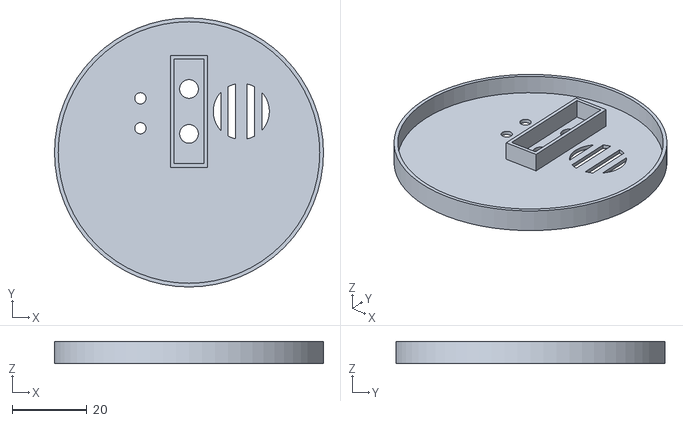
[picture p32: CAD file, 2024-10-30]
3d_models/spiders/Spider Pattern Mk 2.stl
72.0 x 72.0 x 6.00

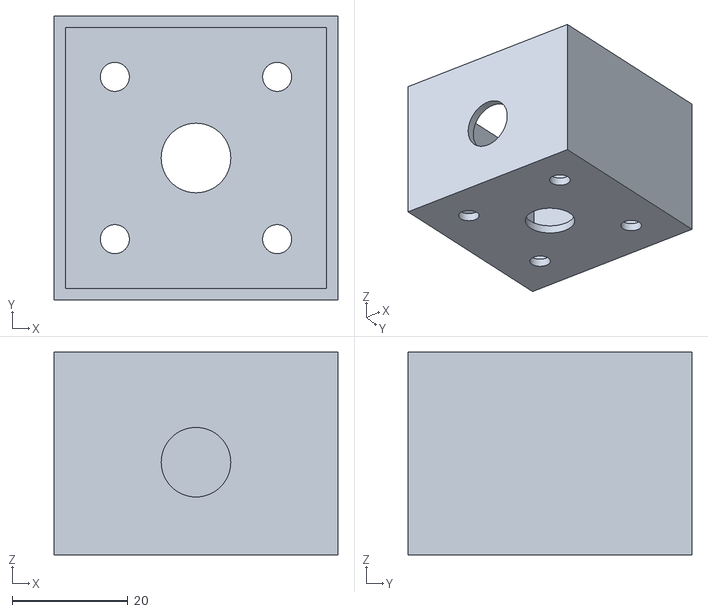
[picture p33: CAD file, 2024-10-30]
3d_models/ultrasonic/Small Ultrasonic Box.stl
49.0 x 49.0 x 35.0

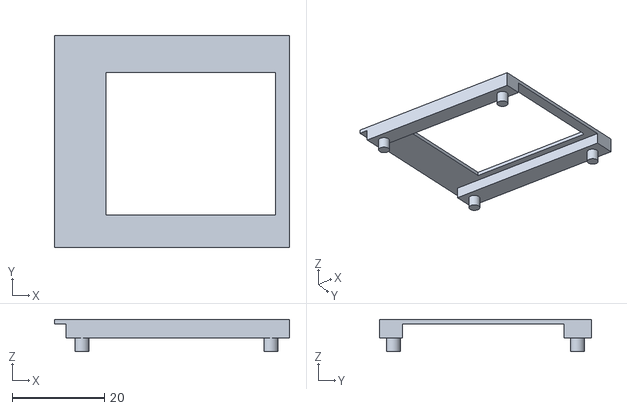
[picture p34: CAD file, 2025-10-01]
3d_models/eyes/Screen cover single.stl
51.0 x 46.0 x 7.00

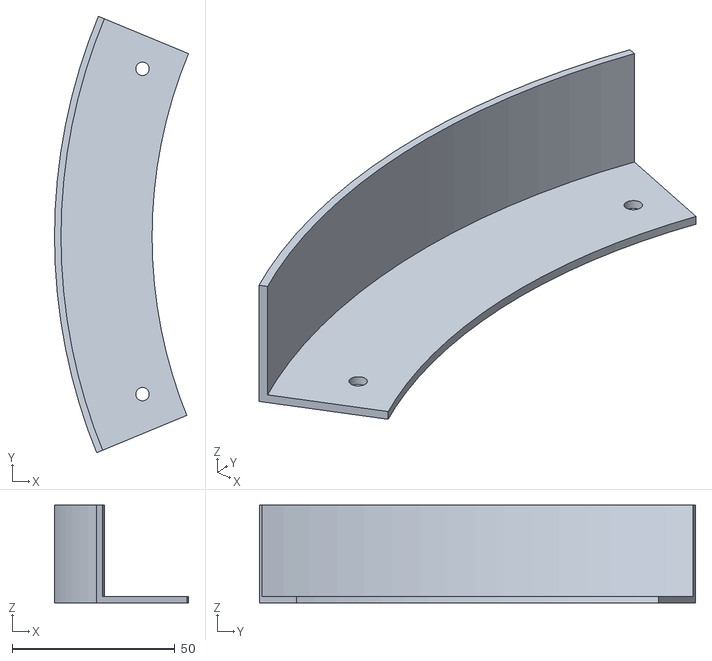
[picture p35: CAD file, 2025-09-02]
3d_models/fire/Eigth turn with holes.stl
41.2 x 134.1 x 30.0

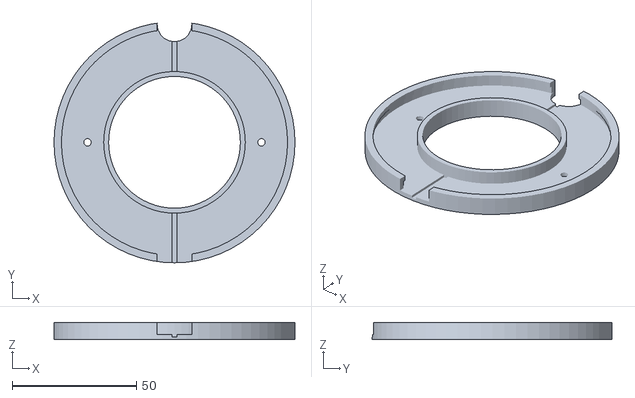
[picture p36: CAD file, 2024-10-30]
3d_models/lightning/24 x Neopixel ring holder 92mm.stl
97.0 x 96.4 x 7.00

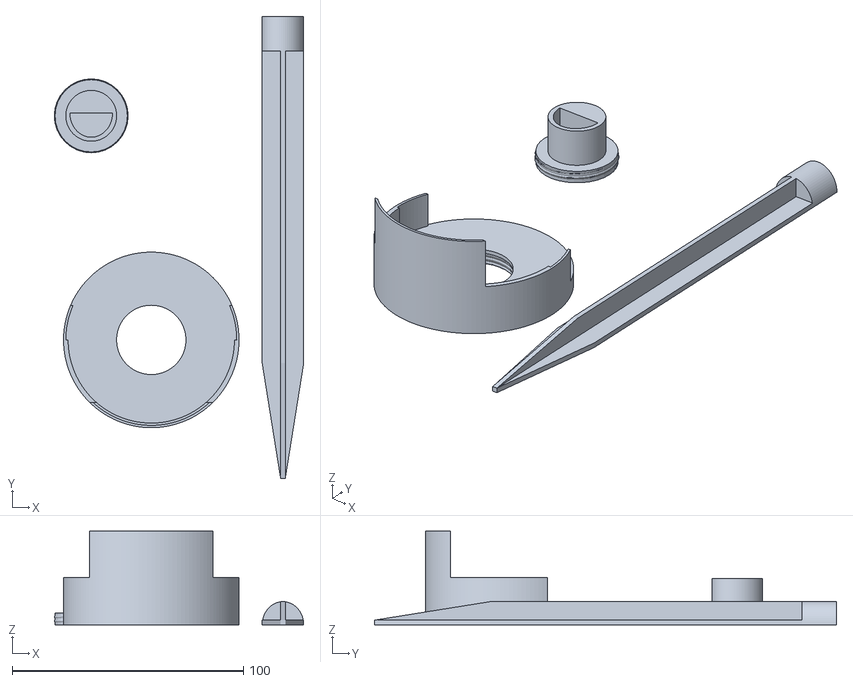
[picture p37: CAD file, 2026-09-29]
3d_models/skull_jar/Skull Mount.stl
108.0 x 200.0 x 40.5

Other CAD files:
3d_models/speaker/Speaker Box Cover.stl
3d_models/spiders/Holder Mk 2.stl
3d_models/ultrasonic/Small Ultrasonic Clip.stl
3d_models/fire/4xAA Battery Holder.stl
3d_models/Mark III Nodes/screwable parts.stl
3d_models/fire/Cable clip.stl
3d_models/fire/Circuit Board Holder.stl
3d_models/fire/Quater turn.stl
3d_models/skull_jar/Mason_jar_12mm_hole.stl
3d_models/skull_jar/Mason_jar_id_with_57mm_clip.stl
3d_models/skull_jar/Neopixel_ring_holder_52mm_base.stl
3d_models/skull_jar/Neopixel_ring_holder_52mm_base_tall.stl
3d_models/skull_jar/Neopixel_ring_holder_57mm_clip.stl
3d_models/spiders/Holder.stl
3d_models/spiders/Spider Pattern.stl
3d_models/ultrasonic/Ultrasonic Box Plugs.stl
3d_models/ultrasonic/Ultrasonic Box.stl
3d_models/ultrasonic/Ultrasonic Clip.stl

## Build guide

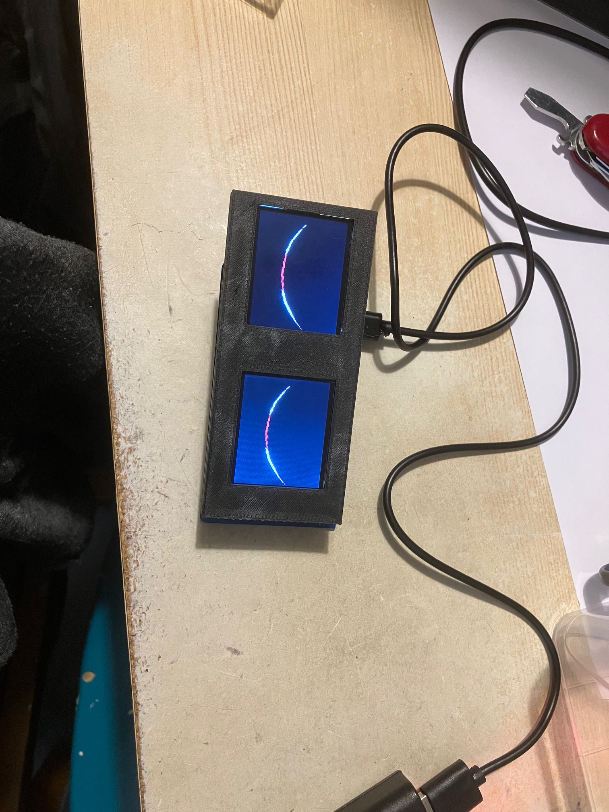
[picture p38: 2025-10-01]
microcontroller/makecode-arcade/eyes/constructing_new_eyes/5b_new_eyes_running.jpg

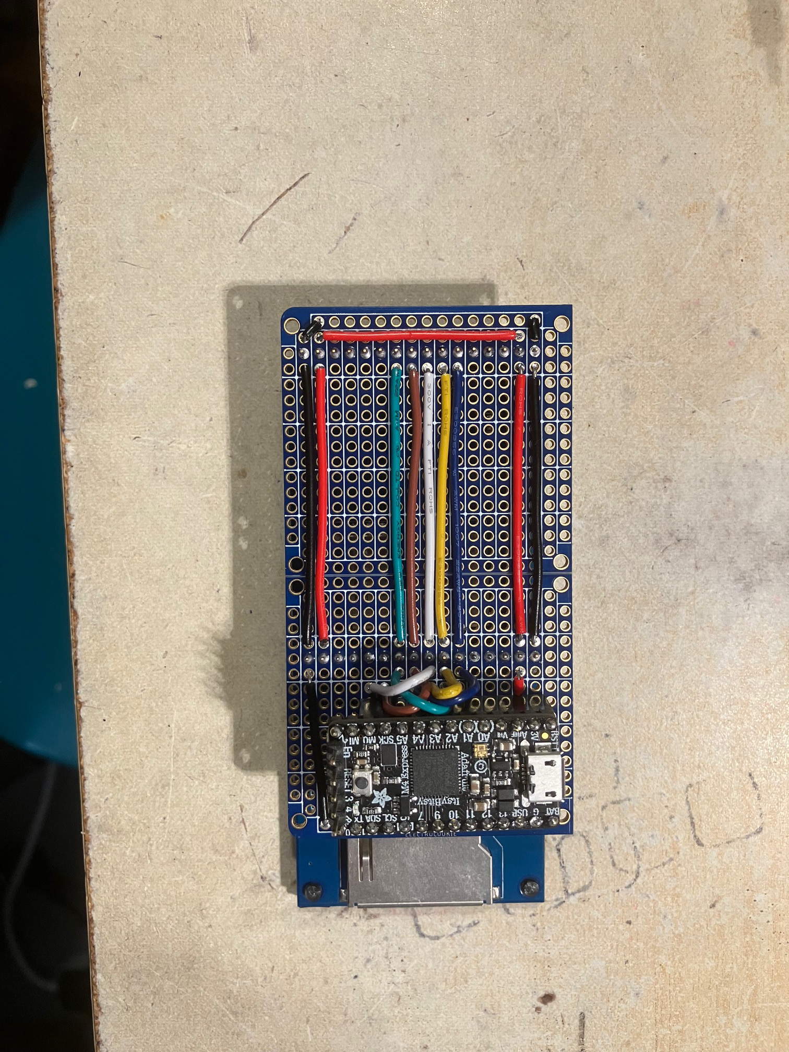
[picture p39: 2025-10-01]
microcontroller/makecode-arcade/eyes/constructing_new_eyes/4a_new_circuit_board.jpg

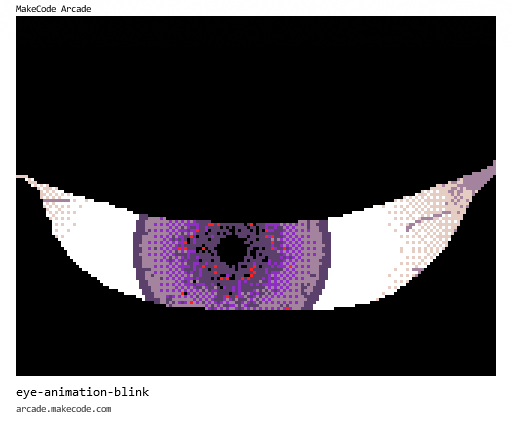
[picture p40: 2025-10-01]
microcontroller/makecode-arcade/eyes/original/arcade-eye-animation-blink.png

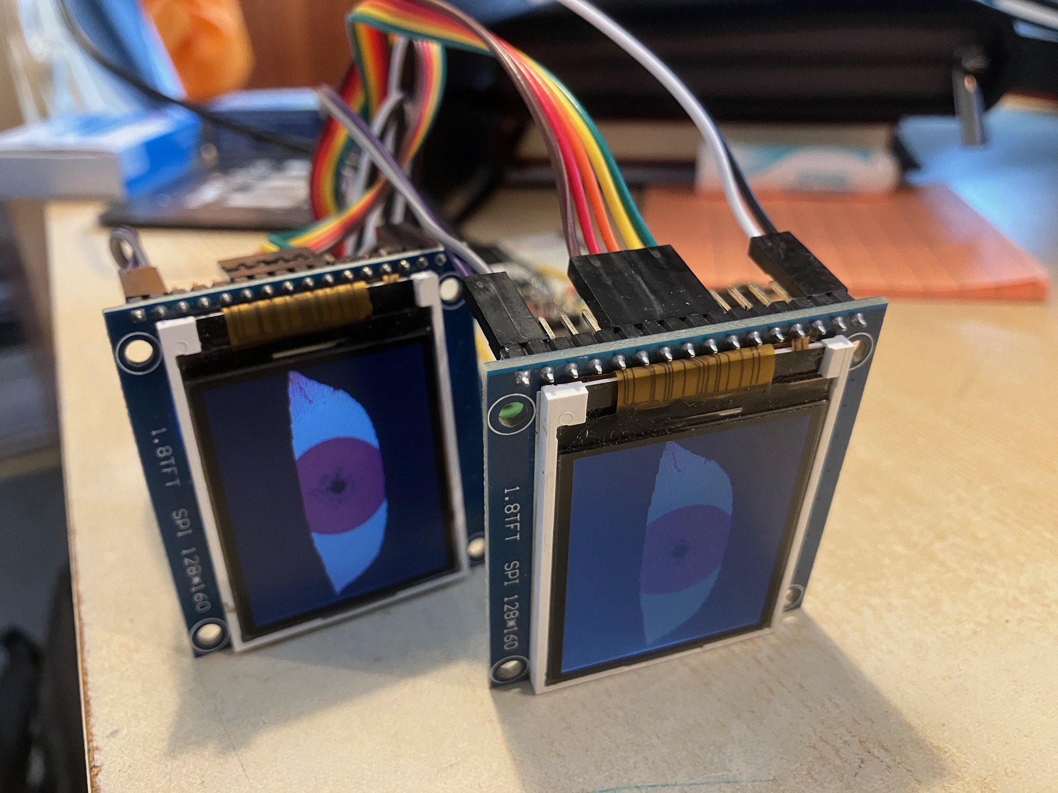
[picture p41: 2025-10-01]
microcontroller/makecode-arcade/eyes/constructing_new_eyes/2a_original_creepby_head_insides_removed_.jpg

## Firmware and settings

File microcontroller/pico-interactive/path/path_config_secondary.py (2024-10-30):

# NOTE: Rename this to config.py on the secondary node path microcontroller.
# This code runs on a standard Pico 2040
import board

PRIMARY_NODE = False

BUTTON_PIN = board.GP26
AUDIO_PIN = board.GP22
ULTRASONIC_TRIGGER_PIN = board.GP17
ULTRASONIC_ECHO_PIN = board.GP16

SKULL_PINS = [board.GP5, board.GP7, board.GP9, board.GP10, board.GP8, board.GP6]
SKULL_COLOUR = ORANGE
SKULL_BRIGHTNESS = 1.0
SKULL_SPEED = 0.1

TRIGGER_PIN = board.GP0
TRIGGER_DURATION = 40

REPORT_RAM = False
REPORT_RAM_PERIOD = 10

from interactive.log import CRITICAL

LOG_LEVEL = CRITICAL

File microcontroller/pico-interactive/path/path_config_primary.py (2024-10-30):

# NOTE: Rename this to config.py on the primary node path microcontroller.
# This code runs on a Pimoroni Tiny 2040
import board

PRIMARY_NODE = True

BUTTON_PIN = board.GP0
AUDIO_PIN = board.GP26

SKULL_PINS = [board.GP1, board.GP4, board.GP6, board.GP5, board.GP3, board.GP2]
SKULL_COLOUR = ORANGE
SKULL_BRIGHTNESS = 1.0
SKULL_SPEED = 0.1

TRIGGER_PIN = board.GP29
TRIGGER_DURATION = 40

REPORT_RAM = False
REPORT_RAM_PERIOD = 10

from interactive.log import CRITICAL

LOG_LEVEL = CRITICAL

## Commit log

2024-10-30 Initial commit of 2024 Halloween project.
    [24 x Neopixel ring cover 92mm.stl, 24 x Neopixel ring holder 92mm.stl, Connector Box.stl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]
2025-09-02 Added 3D models for fireplace
    [4xAA Battery Holder.stl, Cable clip.stl, Circuit Board Holder.stl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]
2025-10-01 Skull holder 3D model
    [Skull Mount.stl]
2025-10-01 Re-organise for Haloween 2025 (#4)
    [Screen cover double.stl, Screen cover single.stl]
2026-07-18 First attempt at the mark 3 box
    [screwable parts.stl]
2026-09-23 Minor rework of structure
    [cauldron_code.py, fire_code.py, graveyard_code.py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]
2026-09-26 Uploaded latest 3D models for Mark III nodes
    [Mark III v1.7 - Speaker v1.2.stl, Mark III v1.7 - baseline parts.stl, screwable parts.stl]
2026-10-06 Updated models with latest mark 3 speaker node
    [Mark III v1.7 - Speaker v1.2.stl, plain_lid.stl]
2026-10-07 Modified the cauldron and fire code to operate on a Pico 2W Mark 3 node. (#6)
2026-10-11 Updated with most of the weekends work - shelly sensor platform, new and repurposed nodes in witches house, preaprations for 4 additional nodes (#8)
2026-10-16 Add support for 3 zones and the mounts for the sensors. (#9)
2026-10-17 Add support for 3 shelly sensors (#10)
2026-10-18 Updated 3D prints for porch hanger and blackboard stand to make them stronger.
